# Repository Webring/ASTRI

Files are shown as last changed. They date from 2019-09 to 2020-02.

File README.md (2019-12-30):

### Автоматический диспенсер таблеток "Астри II"
Устройство контролирующее прием лекарственных препаратов. Подойдет для людей пожилых людей и людей с нарушениями памяти.
Главное отличие этой разработки от других - это простота использования. Человеку нужно всего лишь подойти и взять таблетку.
Это устройство напоминает и контролирует прием лекарственных препаратов. Данное устройство актуально, так как многие люди пьют различные препараты на постоянной основе. В основном оно нацелено на пенсионеров, людей с нарушениями памяти и людей, принимающих таблетки на постоянной основе.  Для использования устройства данной категорией людей оно должно быть максимально упрощено по сравнению с аналогами. Когда прозвучит звуковой сигнал, человеку достаточно только подойти к устройству и выпить таблетку (предварительно нужно загрузить препараты и установить время выдачи). Также немаловажным является то, что в ASTRI II предусмотрена многопрофильная система, что позволяет пользоваться устройством всей семьей (до 10 человек) или использовать ее в стационаре. Для того, чтобы человек не принял двойную дозу препарата, забытого принять ранее (в случае, если человек не был дома, или не мог подойти), предусмотрена система сброса невыпитых таблеток. После истечения срока выдачи препарата (то есть время через которое таблетка будет утилизирована), таблетка сбрасывается в специальную емкость, закрываемую на ключ. В конструкции 2 барабана по 15 ячеек каждый. Объем ячейки 8.4 см³. Информация о необходимых функциях, конструктивных особенностях получена от людей, нуждающихся в этом устройстве. 
##### Автор: Васильев Михаил

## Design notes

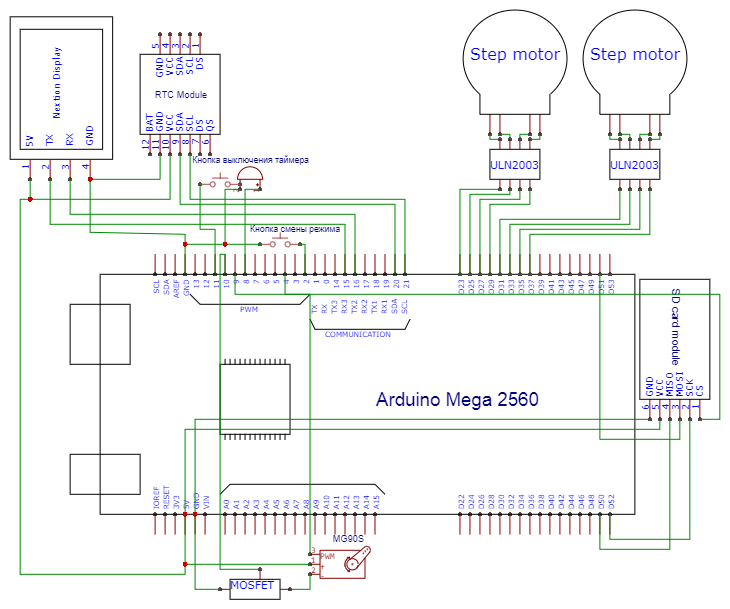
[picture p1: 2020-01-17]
Docs/schematicCircuit.png

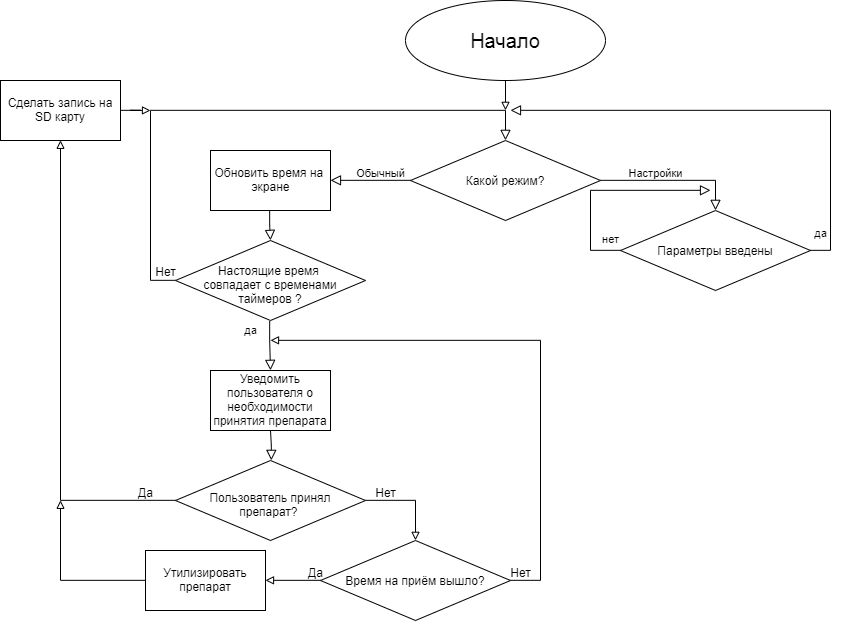
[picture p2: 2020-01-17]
Docs/programScheme.png

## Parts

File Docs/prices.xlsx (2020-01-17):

Наименование | Количество,шт | Розничная цена в России, руб | Розничная цена в Китае, руб | Оптовая цена в Китае, руб
Arduino mega 2560 pro mini | 1 | 1021 | 468.5
Arduino nano | 1 | 284.05 | 107.5
Wemos d1 mini | 1 | 270.758 | 119.35
Дисплей Nextion | 1 | 2355 | 800
Модуль SD карты | 1 | 89 | 27.94
SD карта | 1 | 250 | 83.8
Шаговый двигатель 28byj-48 | 2 | 240 | 92.78
Драйвер двигателя ULN2003 | 2 | 50 | 32.38
Модуль реального времени DS1307 | 1 | 97 | 34.92
Сервопривод mg90s | 1 | 160 | 124.56
Пьезо-пищалка | 1 | 50 | 8.8
Сенсорная кнопка TTP223 | 1 | 25 | 12
Переключатель | 1 | 15 | 3
Замок | 1 | 92.2 | 51.3
Стилус | 1 | 137 | 32.38
Итого: |  | 5426.008 | 2124.37 | 0

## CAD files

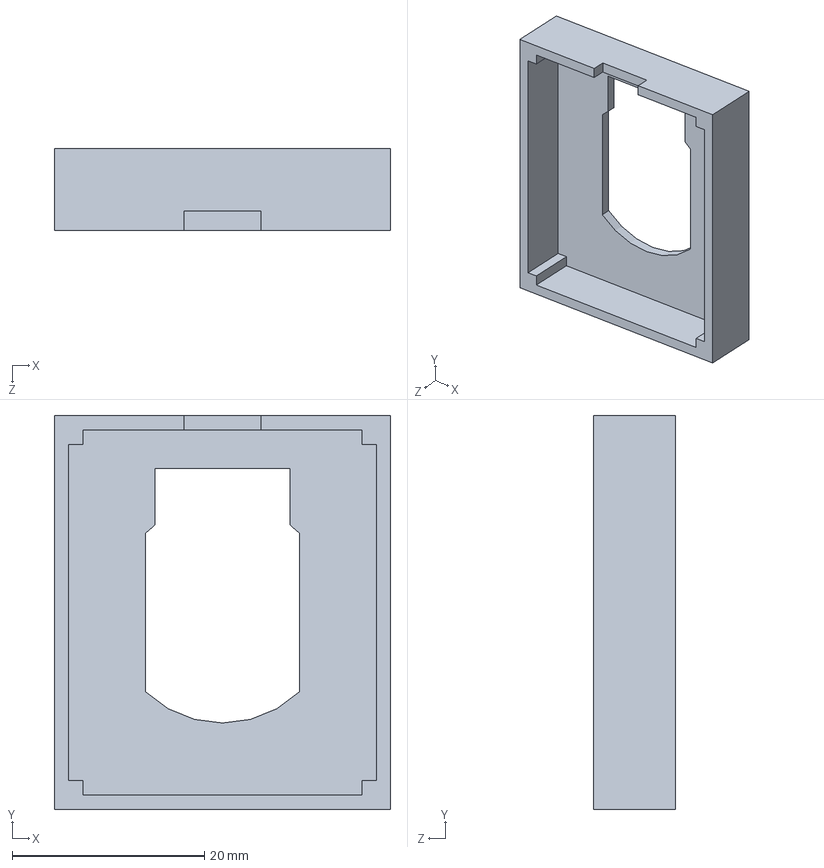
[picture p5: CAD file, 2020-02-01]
Mechanical/RTC bottom.SLDPRT
35.0 x 41.0 x 8.50 mm

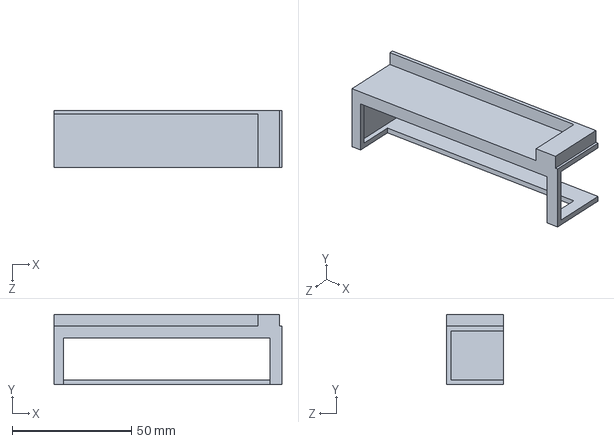
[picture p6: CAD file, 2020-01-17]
Mechanical/trayHolder.SLDPRT
95.5 x 29.5 x 24.0 mm

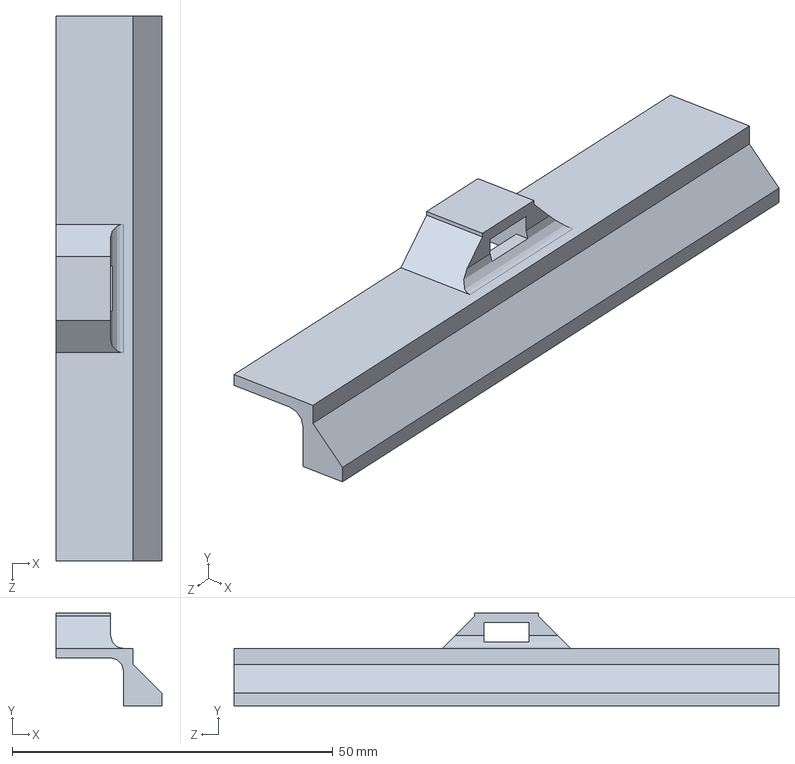
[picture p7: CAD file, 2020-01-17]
Mechanical/tableButtonStand.SLDPRT
16.5 x 14.5 x 85.0 mm

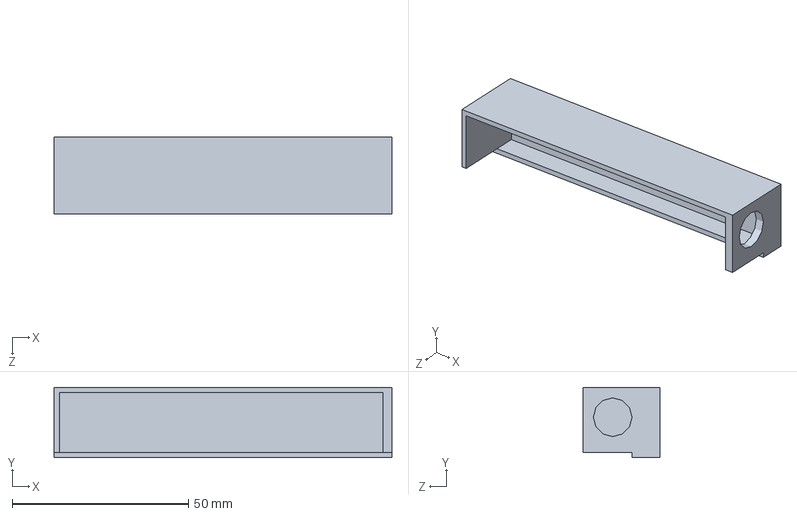
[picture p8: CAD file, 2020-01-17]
Mechanical/trayForDroppedPills.SLDPRT
96.0 x 20.0 x 22.0 mm

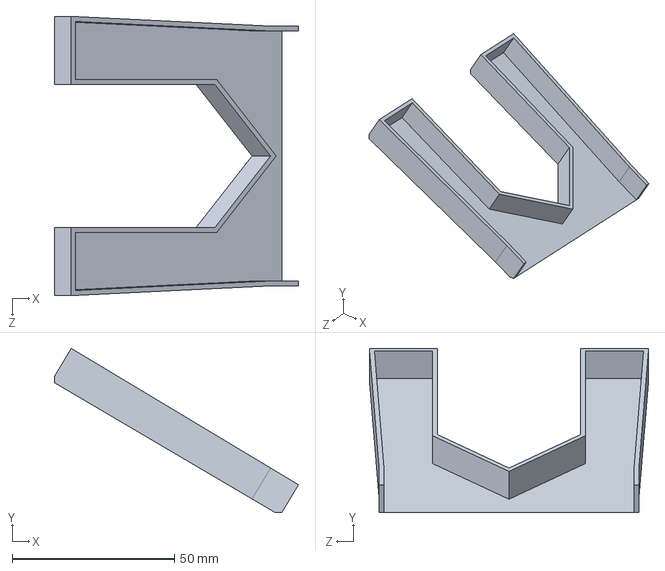
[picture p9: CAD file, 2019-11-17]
Mechanical/Gutter.SLDPRT
75.1 x 50.6 x 86.0 mm

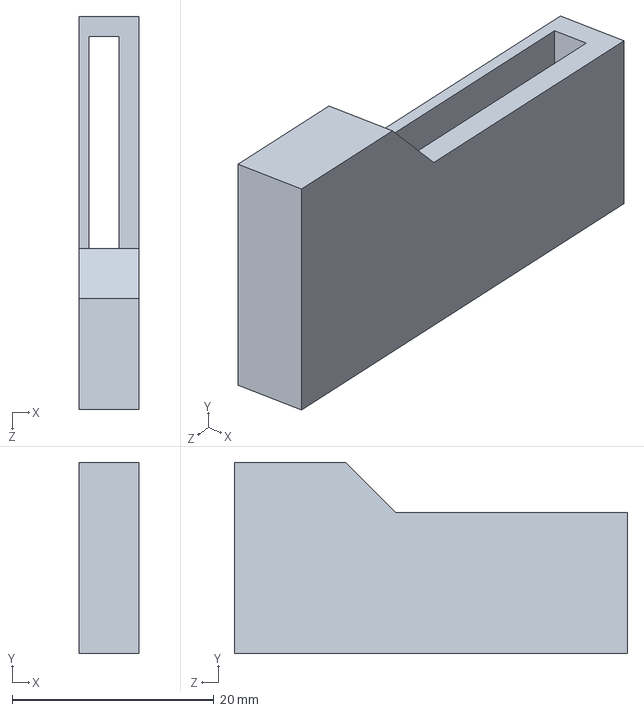
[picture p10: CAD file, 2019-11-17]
Mechanical/connector mount table.SLDPRT
6.00 x 19.0 x 39.0 mm

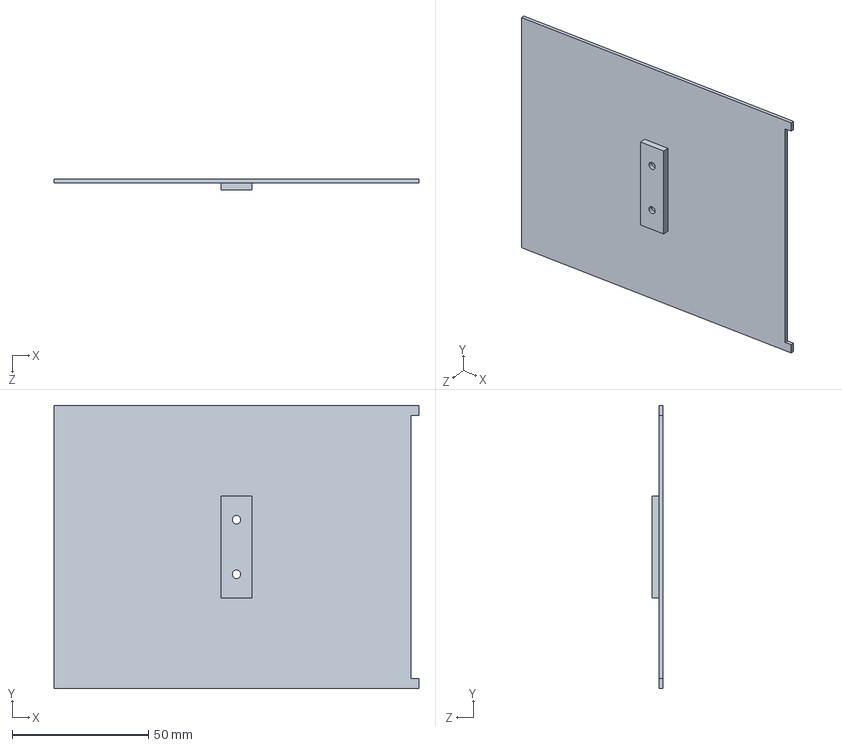
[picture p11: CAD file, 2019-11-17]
Mechanical/bottom.SLDPRT
134.0 x 104.0 x 4.20 mm

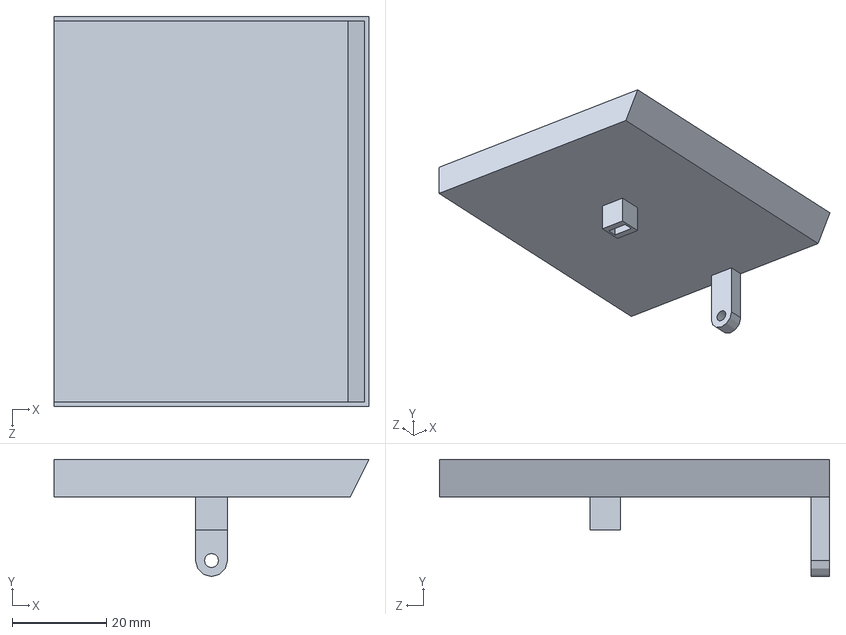
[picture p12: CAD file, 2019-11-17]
Mechanical/new table top.SLDPRT
67.0 x 24.9 x 83.0 mm

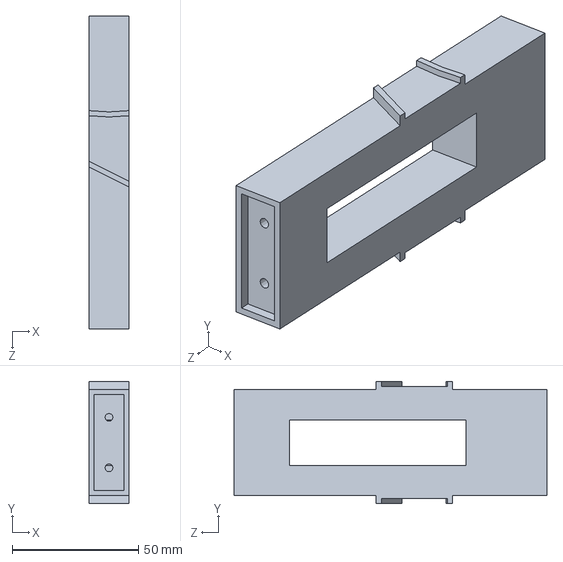
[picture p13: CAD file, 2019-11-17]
Mechanical/motor mount to floor.SLDPRT
16.0 x 48.5 x 124.0 mm

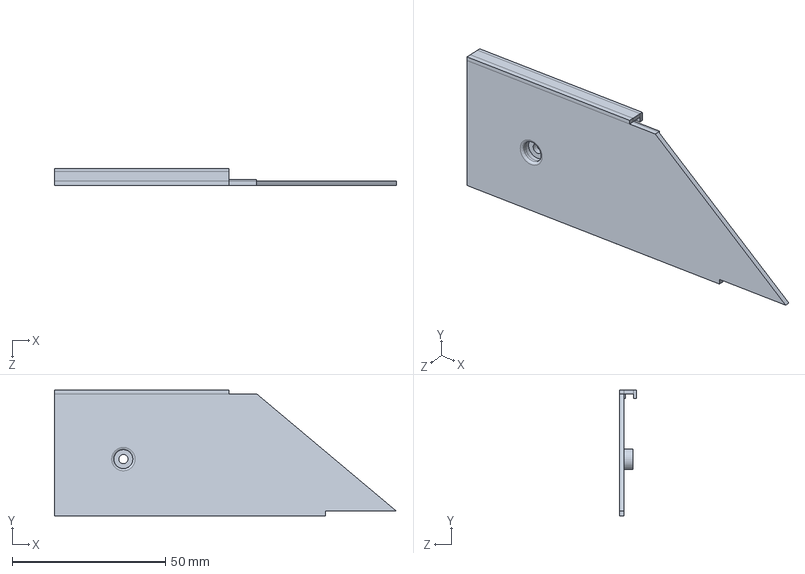
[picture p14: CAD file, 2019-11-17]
Mechanical/left side of table.SLDPRT
111.7 x 41.0 x 5.70 mm

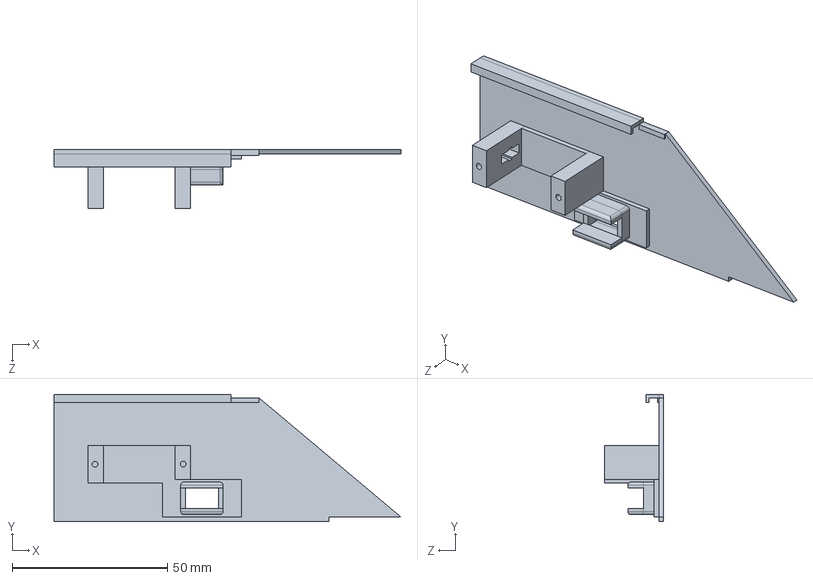
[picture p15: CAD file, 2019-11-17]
Mechanical/right side of table.SLDPRT
111.7 x 41.0 x 19.0 mm

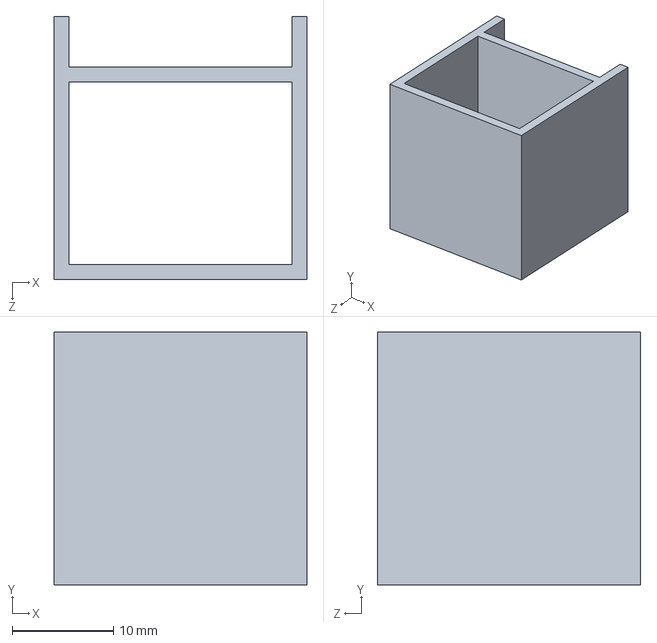
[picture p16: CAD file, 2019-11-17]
Mechanical/stand for power supplies.SLDPRT
25.0 x 25.0 x 26.0 mm

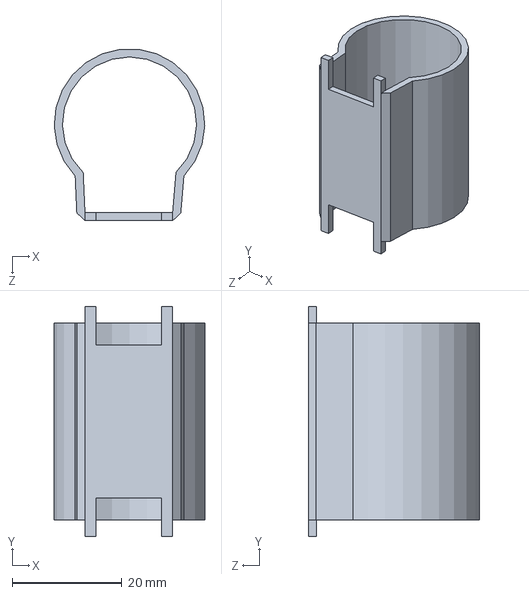
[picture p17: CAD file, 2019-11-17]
Mechanical/motor to floor mount.SLDPRT
27.5 x 42.0 x 31.3 mm

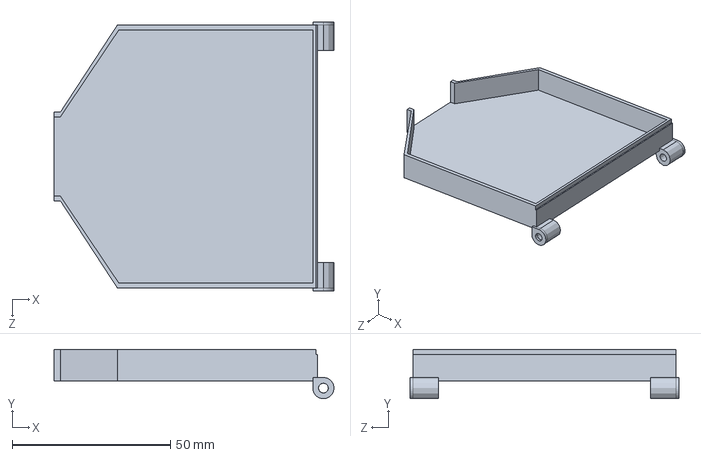
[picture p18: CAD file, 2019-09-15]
Mechanical/table top.SLDPRT
88.5 x 15.6 x 85.0 mm

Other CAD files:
Mechanical/front side of table.SLDPRT
Mechanical/table bottom.SLDPRT
Mechanical/switch nozzle.SLDPRT
Mechanical/drum head.SLDPRT
Mechanical/drum body.SLDPRT
Mechanical/drum.SLDPRT
Mechanical/motor mount to drum.SLDPRT

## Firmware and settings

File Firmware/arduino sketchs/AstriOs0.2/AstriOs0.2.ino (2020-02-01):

#include <EEPROM.h>
#include <iarduino_RTC.h>
#include <Nextion.h>
#include <Stepper.h>
#include <SD.h>
#include <SPI.h>
#include <TMRpcm.h>
#include <Servo.h>


//int enteredPills1; // Количество таблеток при добавлении таймера
//int enteredPills2;

char* pageId = "0";
unsigned long lastTime, waitTime, buzzerLastTime, timerStartTime;

Nextion Display(Serial2, 9600);
iarduino_RTC time(RTC_DS1307);
Stepper stepper1(64, 29, 25, 27, 23);
Stepper stepper2(64, 10, 9, 8, 11);
#define BUZZER_PIN 5
#define SD_PIN 4
#define MODE_SWITCH 2
#define OFF_BUTTON 3
#define SERVO_PIN 6
#define SERVO_SWITCH_PIN 7
//------------------------------------------------------------------
#define timerOffset 15000 //В милисекундах
//------------------------------------------------------------------

void(* reset) (void) = 0; // Перезагрузка MK

Servo tableServo;

void setup() {
  pinMode(SERVO_SWITCH_PIN, OUTPUT);
  tableServo.attach(SERVO_PIN);
  Serial.begin(19200);
  stepper1.setSpeed(40);
  stepper2.setSpeed(40);
  goToPage("0"); //инициализируем дисплей, а точнее первую страницу
  time.begin();
  sdInit();
  //playSound();
  stepperDisable();
}

void notificationWindow(char* ititle, char* itext, char* ibuttonText = "Ок") {//nextion
  goToPage("7");
  setText("t0", ititle);
  setText("t1", itext);
  setText("b0", ibuttonText);
  while (Display.listen() != "65 7 2 1 ffff ffff ffff");
}

void loop() {

  if (digitalRead(MODE_SWITCH)) {
    displayTime();
    for (int n = 1; n <= EEPROM.read(0); n++) {
      if (EEPROM.read(cellFormula(n, 1)) == time.Hours && EEPROM.read(cellFormula(n, 2)) == time.minutes && millis() - lastTime >= waitTime) { //формула обращения к ячейке n*7-p+3
        lastTime = millis();
        waitTime = 59800;
        bool pillTaken = true;
        goToPage("7");
        setText("t0", "Внимание!");
        setText("t1", "Производится выдача лекарств!");
        setText("b0", "");
        delay(500);
        for (int cellNumber = 0; cellNumber < EEPROM.read(cellFormula(n, 3)); cellNumber ++) {
          drumRotate();
          delay(300);
        }
        bool sdInit = SD.begin(SD_PIN);
        if (sdInit) {
          char nameChar[15];
          String nameStr = getName(EEPROM.read(cellFormula(n, 5)) - 1);
          nameStr.toCharArray(nameChar, 16);
          setText("t0", nameChar);
        }
        else {
          setText("t0", "Человек " + char(EEPROM.read(cellFormula(n, 5))));
        }
        setText("t1", "Возьмите пожалуйста таблетки!");
        setText("b0", "Взял");
        timerStartTime = millis();
        while (Display.listen() != "65 7 2 1 ffff ffff ffff" && digitalRead(OFF_BUTTON) == 0) {
          if ((millis() % 1000) > 500) {
            tone(BUZZER_PIN, 700);
          }
          else {
            noTone(BUZZER_PIN);
          }
          if (timerStartTime + timerOffset < millis()) {
            tone(BUZZER_PIN, 200);
            setText("t0", "Внимание!");
            setText("t1", "Производится утилизация! Уберите руки!");
            setText("b0", "");
            utilizate();
            pillTaken = false;
            break;
          }
        }
        noTone(BUZZER_PIN);
        if (sdInit) {
          if (pillTaken) {
            writeLog(time.gettime("d.m.Y;H:i"), String(EEPROM.read(cellFormula(n, 5))), "\xd2\xe0\xe1\xeb\xe5\xf2\xea\xe0 \xc2\xe7\xff\xf2\xe0");
          }
          else {writeLog(time.gettime("d.m.Y;H:i"), String(EEPROM.read(cellFormula(n, 5))), "\xcf\xf0\xe5\xef\xe0\xf0\xe0\xf2\xfb \xed\xe5 \xe1\xfb\xeb\xe8 \xef\xf0\xe8\xed\xff\xf2\xfb, \xef\xee\xfd\xf2\xee\xec\xf3 \xee\xed\xe8 \xf3\xf2\xe8\xeb\xe8\xe7\xe8\xf0\xee\xe2\xe0\xed\xfb!");}
        }
      }
    }
  }
  else {
    if (pageId != "1") {
      goToPage("1");
    }
    String nexMessage = Display.listen();
    if (nexMessage != "") {


      if (nexMessage == "65 1 4 1 ffff ffff ffff") {
        time.settime(0, numInput("Введите минуты:", 0, 59), numInput("Введите часы:", 0, 23), numInput("Введите день:", 1, 31), numInput("Введите месяц:", 1, 12), numInput("Введите год:", 0, 99), weekDayInput());
        delay(100);
        reset();
      }
      if (nexMessage == "65 1 2 1 ffff ffff ffff") {
        timerDelete();
      }
      if (nexMessage == "65 1 1 1 ffff ffff ffff") {
        int numberOfTimer = EEPROM.read(0) + 1;
        EEPROM.update(0, numberOfTimer);
        delay(10);
        EEPROM.update(cellFormula(numberOfTimer, 1), numInput("Введите часы:", 0, 23));
        delay(10);
        EEPROM.update(cellFormula(numberOfTimer, 2), numInput("Введите минуты:", 0, 59));
        delay(10);
        EEPROM.update(cellFormula(numberOfTimer, 3), numInput("Кол-во таблеток в I:", 0, 15));
        delay(10);
        EEPROM.update(cellFormula(numberOfTimer, 4), numInput("Кол-во таблеток в II:", 0, 15));
        delay(10);
        EEPROM.update(cellFormula(numberOfTimer, 5), numInput("ID пользователя", 1, 9));
        delay(10);
        reset();
      }

    }
    delay(100);
  }
}



int cellFormula(int timerNumber, int timerParametr) {
  return (10 + timerNumber * 7 - (7 - timerParametr));
}

void utilizate() {
  digitalWrite(SERVO_SWITCH_PIN, HIGH);
  tableServo.write(50);
  delay(1000);
  tableServo.write(5);
  delay(1000);
  digitalWrite(SERVO_SWITCH_PIN, LOW);
}

void stepperDisable() {
  digitalWrite(23, LOW);
  digitalWrite(25, LOW);
  digitalWrite(27, LOW);
  digitalWrite(29, LOW);
}

void drumRotate() {
  /*
  Serial.println("start");
  stepper1.step(25);
  delay(500);
  for (int stepNum = 0; stepNum < 85; stepNum++) {
    int ar = analogRead(A0);
    Serial.print("Sensor value "); Serial.println(ar);
    if (ar >= 573) {
      Serial.print("break rotate on sensor value "); Serial.println(ar);
      break;
    }
    stepper1.step(2);
    delay(10);
  }
  Serial.println("basic rotate end");
  delay(500);
  stepper1.step(24);
  Serial.println("offset rotate end");*/
  stepper1.step(145);
  stepperDisable();
}

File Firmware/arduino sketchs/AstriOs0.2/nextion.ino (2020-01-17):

String bcode;

void goToPage(char* id) {
  pageId = id;
  Display.init(id);
}

void setText(String element, char* Str) {
  Display.setComponentText(element, convert(Str));// Изменяет текст
  delay(100);
}

int numInput(char* text, int Min, int Max) {
  if (pageId != "2") {
    goToPage("2");
  }
  setText("t0", text);
  setText("t1", "0");
  int numIn[2] = {0, 0};//1 цифра, 2 цифра
  int numNumber = 0;
  int numOut = 0;
  char numSOut[2];
  String numStr;
  while (1) {
    bcode = Display.listen();//обязательно нужна для корректной работы

    if (bcode != "") {
      if (numNumber < 2 && bcode != "65 2 d 1 ffff ffff ffff" && bcode != "65 2 b 1 ffff ffff ffff") {
        if (bcode == "65 2 c 1 ffff ffff ffff") {
          numIn[numNumber] = 0;
        }
        if (bcode == "65 2 1 1 ffff ffff ffff") {
          numIn[numNumber] = 1;
        }
        if (bcode == "65 2 3 1 ffff ffff ffff") {
          numIn[numNumber] = 2;
        }
        if (bcode == "65 2 4 1 ffff ffff ffff") {
          numIn[numNumber] = 3;
        }
        if (bcode == "65 2 5 1 ffff ffff ffff") {
          numIn[numNumber] = 4;
        }
        if (bcode == "65 2 6 1 ffff ffff ffff") {
          numIn[numNumber] = 5;
        }
        if (bcode == "65 2 7 1 ffff ffff ffff") {
          numIn[numNumber] = 6;
        }
        if (bcode == "65 2 8 1 ffff ffff ffff") {
          numIn[numNumber] = 7;
        }
        if (bcode == "65 2 9 1 ffff ffff ffff") {
          numIn[numNumber] = 8;
        }
        if (bcode == "65 2 a 1 ffff ffff ffff") {
          numIn[numNumber] = 9;
        }
        if (bcode != "65 2 c 1 ffff ffff ffff" || numNumber == 1) {
          numNumber++;
        }
      }
      if (numNumber == 2) {
        numOut = numIn[0] * 10 + numIn[1];
      }
      if (numNumber == 1) {
        numOut = numIn[0];
      }
      if (numNumber == 0) {
        numOut = 0;
      }
      if (bcode == "65 2 b 1 ffff ffff ffff") {
        if (numOut <= Max && numOut >= Min) {
          return numOut;
          break;
        }
        else {
          setText("t0", "Неверное значение!");
          delay(1500);
          setText("t0", text);
        }
      }

      if (bcode == "65 2 d 1 ffff ffff ffff") {
        if (numNumber > 0) {
          numNumber--;
        }
        if (numNumber == 0) {
          numOut = 0;
        }
        if (numNumber == 1) {
          numOut = numIn[0];
        }
        if (numNumber == 2) {
          numOut = numIn[0] * 10 + numIn[1];
        }
      }
      numStr = String(numOut);
      numStr.toCharArray(numSOut, 3);
      setText("t1", numSOut);
    }
    delay(100);//задержка для корректной работы дисплея
  }

}
/*
  void drumInput() {
  goToPage("4");
  enteredPills1 = 0;
  enteredPills2 = 0;
  while (1) {
  bcode = Display.listen();
  Serial.println(bcode);
    Serial.println("bc");
      if (bcode == "65 4 1 1 ffff ffff ffff") {
        Serial.println("ok");
        if (enteredPills1 < 15) {
          enteredPills1++;
        } else {
          enteredPills1 = 0;
        } Display.setComponentText("t0", String(enteredPills1));
      }
      if (bcode == "65 4 3 1 ffff ffff ffff") {
        if (enteredPills1 >= 1) {
          enteredPills1--;
        } else {
          enteredPills1 = 15;
        } Display.setComponentText("t0", String(enteredPills1));
      }
      if (bcode == "65 4 5 1 ffff ffff ffff") {
        if (enteredPills2 < 15) {
          enteredPills2++;
        } else {
          enteredPills2 = 0;
        } Display.setComponentText("t1", String(enteredPills2));
      }
      if (bcode == "65 4 6 1 ffff ffff ffff") {
        if (enteredPills2 >= 1) {
          enteredPills2--;
        } else {
          enteredPills2 = 15;
        } Display.setComponentText("t1", String(enteredPills2));
      }
      if (bcode == "65 4 8 1 ffff ffff ffff") {
        break;
      }
      Serial.println("ee");
    delay(10);
  }
  }*/




void timerDelete() {
  int timerDeleteTimerNumberMax = EEPROM.read(0);
  if (timerDeleteTimerNumberMax == 0) {
    notificationWindow("Уведомление!", "У вас нет таймеров!");
  }
  else {
    goToPage("6");
    int timerDeleteTimerNumber = 1;
    Display.setComponentText("t4", String(EEPROM.read(cellFormula(timerDeleteTimerNumber, 1))) + ":" + String(EEPROM.read(cellFormula(timerDeleteTimerNumber, 2))));
    Display.setComponentText("t2", String(EEPROM.read(cellFormula(timerDeleteTimerNumber, 3))) + ";" + String(EEPROM.read(cellFormula(timerDeleteTimerNumber, 4))));
    Display.setComponentText("t5", String(timerDeleteTimerNumber));
    Display.setComponentText("t7", String(EEPROM.read(cellFormula(timerDeleteTimerNumber, 5))));
    if (EEPROM.read(cellFormula(timerDeleteTimerNumber, 6))) {
      setText("9", "Уведомлять: да");
    }
    else {
      setText("t9", "Уведомлять: нет");

    }
    Display.setComponentText("t10", String(EEPROM.read(cellFormula(timerDeleteTimerNumber, 7))));


    while (1) {
      String bcode = Display.listen();
      if (bcode == "65 6 1 1 ffff ffff ffff") {
        timerDeleteTimerNumber--;
        if (timerDeleteTimerNumber <= 0) {
          timerDeleteTimerNumber = timerDeleteTimerNumberMax;
        }
        Display.setComponentText("t4", String(EEPROM.read(cellFormula(timerDeleteTimerNumber, 1))) + ":" + String(EEPROM.read(cellFormula(timerDeleteTimerNumber, 2))));
        Display.setComponentText("t2", String(EEPROM.read(cellFormula(timerDeleteTimerNumber, 3))) + ";" + String(EEPROM.read(cellFormula(timerDeleteTimerNumber, 4))));
        Display.setComponentText("t5", String(timerDeleteTimerNumber));
        Display.setComponentText("t7", String(EEPROM.read(cellFormula(timerDeleteTimerNumber, 5))));
        if (EEPROM.read(cellFormula(timerDeleteTimerNumber, 6))) {
          setText("t9", "Уведомлять: да");
        }
        else {
          setText("t9", "Уведомлять: нет");

        }
        Display.setComponentText("t10", String(EEPROM.read(cellFormula(timerDeleteTimerNumber, 7))));

      }

      if (bcode == "65 6 f 1 ffff ffff ffff") {
        timerDeleteTimerNumber++;
        if (timerDeleteTimerNumber > timerDeleteTimerNumberMax) {
          timerDeleteTimerNumber = 1;
        }
        Display.setComponentText("t4", String(EEPROM.read(cellFormula(timerDeleteTimerNumber, 1))) + ":" + String(EEPROM.read(cellFormula(timerDeleteTimerNumber, 2))));
        Display.setComponentText("t2", String(EEPROM.read(cellFormula(timerDeleteTimerNumber, 3))) + ";" + String(EEPROM.read(cellFormula(timerDeleteTimerNumber, 4))));
        Display.setComponentText("t5", String(timerDeleteTimerNumber));
        Display.setComponentText("t7", String(EEPROM.read(cellFormula(timerDeleteTimerNumber, 5))));
        if (EEPROM.read(cellFormula(timerDeleteTimerNumber, 6))) {
          setText("t9", "Уведомлять: да");
        }
        else {
          setText("t9", "Уведомлять: нет");

        }
        Display.setComponentText("t10", String(EEPROM.read(cellFormula(timerDeleteTimerNumber, 7))));
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

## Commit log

2019-08-11 First data
    [Барабан.SLDPRT, Барабан2.SLDPRT, Деталь1.SLDPRT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]
2019-08-12 add prices excel file
    [prices.xlsx]
2019-09-15 Add new 3D models and update price table
    [display frame.STL, front side of table.SLDPRT, left side of table.SLDPRT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]
2019-11-17 add PCBs, 3D models, logo, make raw sheme and started writing astriOS
    [Gutter.SLDPRT, bottom.SLDPRT, bottom.STL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]
2020-01-17 Update prices, add 3D models, update AstriOS
    [prices.xlsx, tableButtonStand.SLDPRT, tableButtonStand.STL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]
2020-02-01 update AstriOs
    [RTC bottom.SLDPRT, RTC bottom.STL]
2020-02-03 update AstriConfigurator
    [RTC bottom.STL, bottom.STL, connector mount table.STL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]
